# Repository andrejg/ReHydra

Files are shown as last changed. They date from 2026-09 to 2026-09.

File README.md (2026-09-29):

# ReHydra
An adaptation of the Hydra network card for Atari ST/TT/Falcon series of computers, making it work with obtainable modern RJ45 jacks like Hanrun HR911105A.

The original design (https://www.atariworld.org/hardware/hydra/) was done by Mathias Münch in 2009 and published under Attribution-NonCommercial-ShareAlike 4.0.

This rework is published under the same license.

https://creativecommons.org/licenses/by-nc-sa/4.0/legalcode.txt

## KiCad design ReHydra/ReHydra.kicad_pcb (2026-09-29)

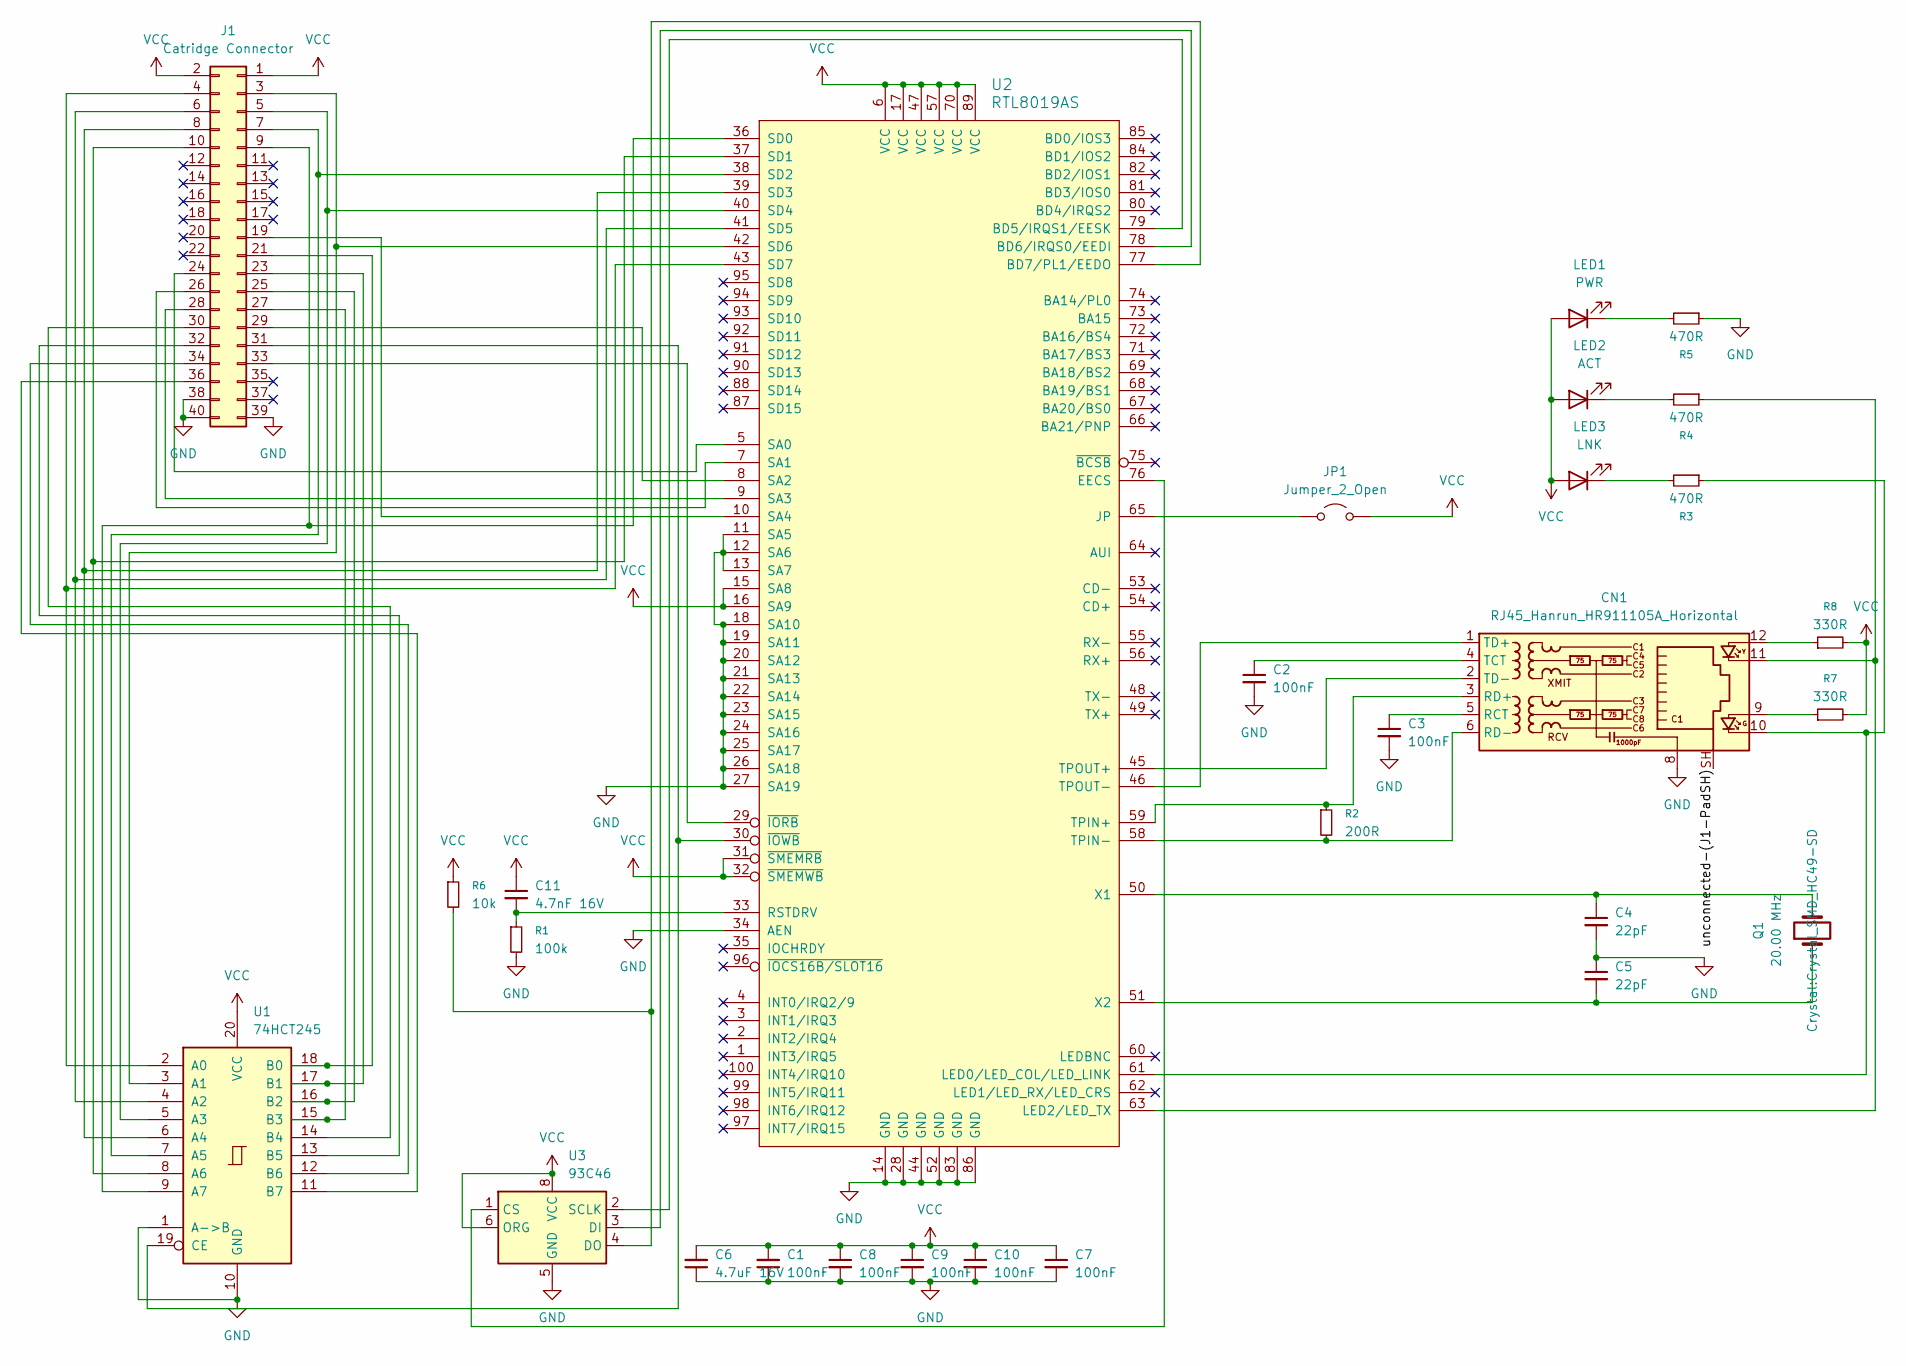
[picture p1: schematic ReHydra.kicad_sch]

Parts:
C1, C2, C3, C7, C8, C9, C10: 100nF; C_0805_2012Metric
C4, C5: 22pF; C_0805_2012Metric
C6: 4.7uF 16V; C_0805_2012Metric
C11: 4.7nF 16V; C_0805_2012Metric
CN1: RJ45_Hanrun_HR911105A_Horizontal
J1: Catridge Connector; Cartridge Connector
JP1: Jumper_2_Open; R_0805_2012Metric
LED1: PWR; LED_0805_2012Metric
LED2: ACT; LED_0805_2012Metric
LED3: LNK; LED_0805_2012Metric
Q1: 20.00 MHz; Crystal_SMD_HC49-SD
R1: 100k; R_0805_2012Metric
R2: 200R; R_0805_2012Metric
R3, R4, R5: 470R; R_0805_2012Metric
R6: 10k; R_0805_2012Metric
R7, R8: 330R; R_0805_2012Metric
U1: 74HCT245; Infineon_SOIC-20W_7.6x12.8mm_P1.27mm
U2: RTL8019AS; PQFP-100
U3: 93C46; SOIC-8_3.9x4.9mm_P1.27mm

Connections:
/unconnected-(J1-PadSH): CN1.SH
GND: C1.1, C2.2, C3.2, C4.2, C5.1, C6.1, C7.2, C8.2, C9.2, C10.2, CN1.8, J1.38, J1.39, J1.40, R1.2, R5.1, U1.1 (A->B), U1.10 (GND), U2.11 (SA5), U2.12 (SA6), U2.13 (SA7), U2.14 (GND), U2.18 (SA10), U2.19 (SA11), U2.20 (SA12), U2.21 (SA13), U2.22 (SA14), U2.23 (SA15), U2.24 (SA16), U2.25 (SA17), U2.26 (SA18), U2.27 (SA19), U2.28 (GND), U2.34 (AEN), U2.44 (GND), U2.52 (GND), U2.83 (GND), U2.86 (GND), U3.5 (GND)
unnamed: CN1.9, R7.1
unnamed: CN1.12, R8.1
unnamed: C3.1, CN1.5 (RCT)
unnamed: CN1.3 (RD+), R2.1, U2.59 (TPIN+)
unnamed: CN1.6 (RD-), R2.2, U2.58 (TPIN-)
unnamed: C2.1, CN1.4 (TCT)
unnamed: CN1.1 (TD+), U2.46 (TPOUT-)
unnamed: CN1.2 (TD-), U2.45 (TPOUT+)
unnamed: J1.3, U1.3 (A1), U2.42 (SD6)
unnamed: J1.4, U1.2 (A0), U2.43 (SD7)
unnamed: J1.5, U1.5 (A3), U2.40 (SD4)
unnamed: J1.6, U1.4 (A2), U2.41 (SD5)
unnamed: J1.7, U1.7 (A5), U2.38 (SD2)
unnamed: J1.8, U1.6 (A4), U2.39 (SD3)
unnamed: J1.9, U1.9 (A7), U2.36 (SD0)
unnamed: J1.10, U1.8 (A6), U2.37 (SD1)
unnamed: J1.19, U2.10 (SA4)
unnamed: J1.21, U1.18 (B0)
unnamed: J1.23, U1.17 (B1)
unnamed: J1.24, U2.5 (SA0)
unnamed: J1.25, U1.16 (B2)
unnamed: J1.26, U2.7 (SA1)
unnamed: J1.27, U1.15 (B3)
unnamed: J1.28, U2.9 (SA3)
unnamed: J1.29, U2.8 (SA2)
unnamed: J1.30, U1.14 (B4)
unnamed: J1.31, U1.19 (CE), U2.30 (~IOWB)
unnamed: J1.32, U1.13 (B5)
unnamed: J1.33, U2.29 (~IORB)
unnamed: J1.34, U1.12 (B6)
unnamed: J1.36, U1.11 (B7)
unnamed: JP1.1 (A), U2.65 (JP)
unnamed: LED1.1 (K), R5.2
unnamed: LED2.1 (K), R4.2
unnamed: LED3.1 (K), R3.2
unnamed: U2.79 (BD5/IRQS1/EESK), U3.2 (SCLK)
unnamed: U2.78 (BD6/IRQS0/EEDI), U3.3 (DI)
unnamed: R6.2, U2.77 (BD7/PL1/EEDO), U3.4 (DO)
unnamed: U2.76 (EECS), U3.1 (CS)
unnamed: CN1.10, R3.1, U2.61 (LED0/LED_COL/LED_LINK)
unnamed: CN1.11, R4.1, U2.63 (LED2/LED_TX)
unnamed: C11.2, R1.1, U2.33 (RSTDRV)
unnamed: C4.1, Q1.2, U2.50 (X1)
unnamed: C5.2, Q1.1, U2.51 (X2)
VCC: C1.2, C6.2, C7.1, C8.1, C9.1, C10.1, C11.1, J1.1, J1.2, JP1.2 (B), LED1.2 (A), LED2.2 (A), LED3.2 (A), R6.1, R7.2, R8.2, U1.20 (VCC), U2.6 (VCC), U2.15 (SA8), U2.16 (SA9), U2.17 (VCC), U2.31 (~SMEMRB), U2.32 (~SMEMWB), U2.47 (VCC), U2.57 (VCC), U2.70 (VCC), U2.89 (VCC), U3.6 (ORG), U3.8 (VCC)

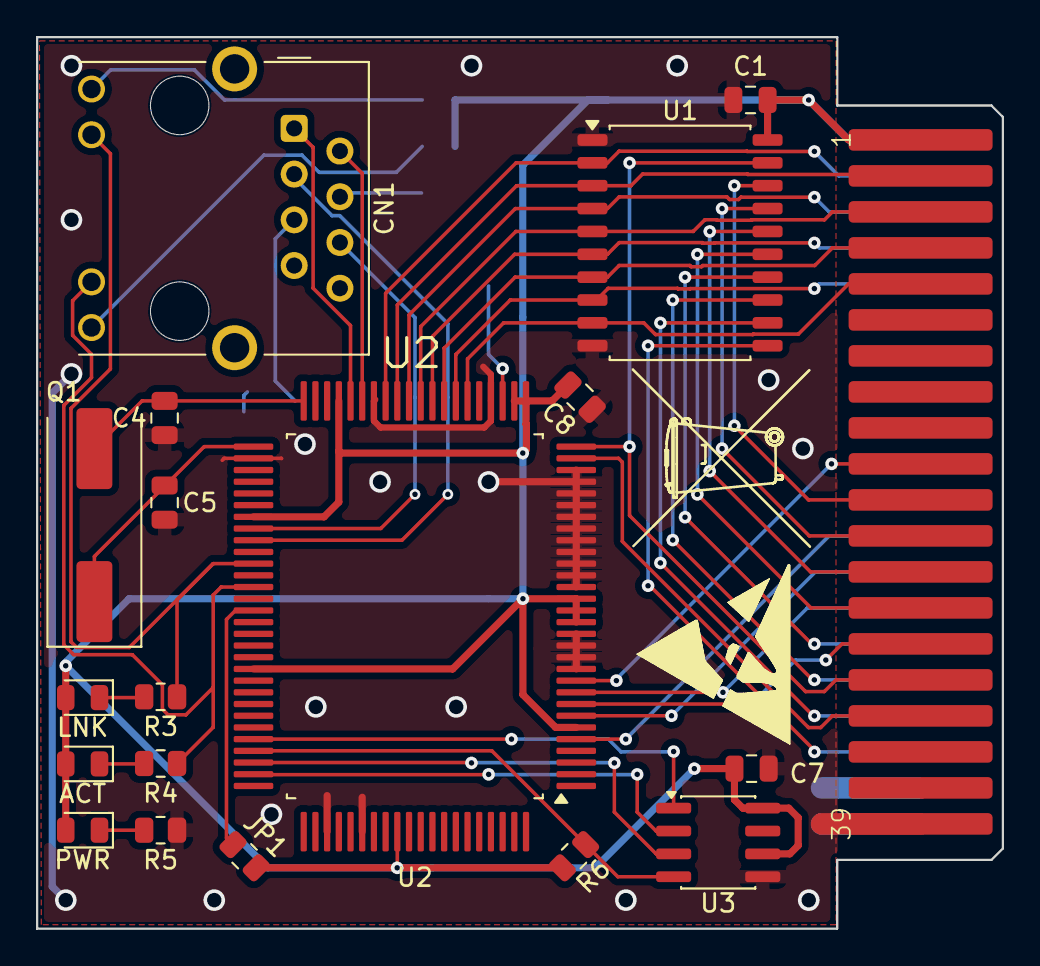
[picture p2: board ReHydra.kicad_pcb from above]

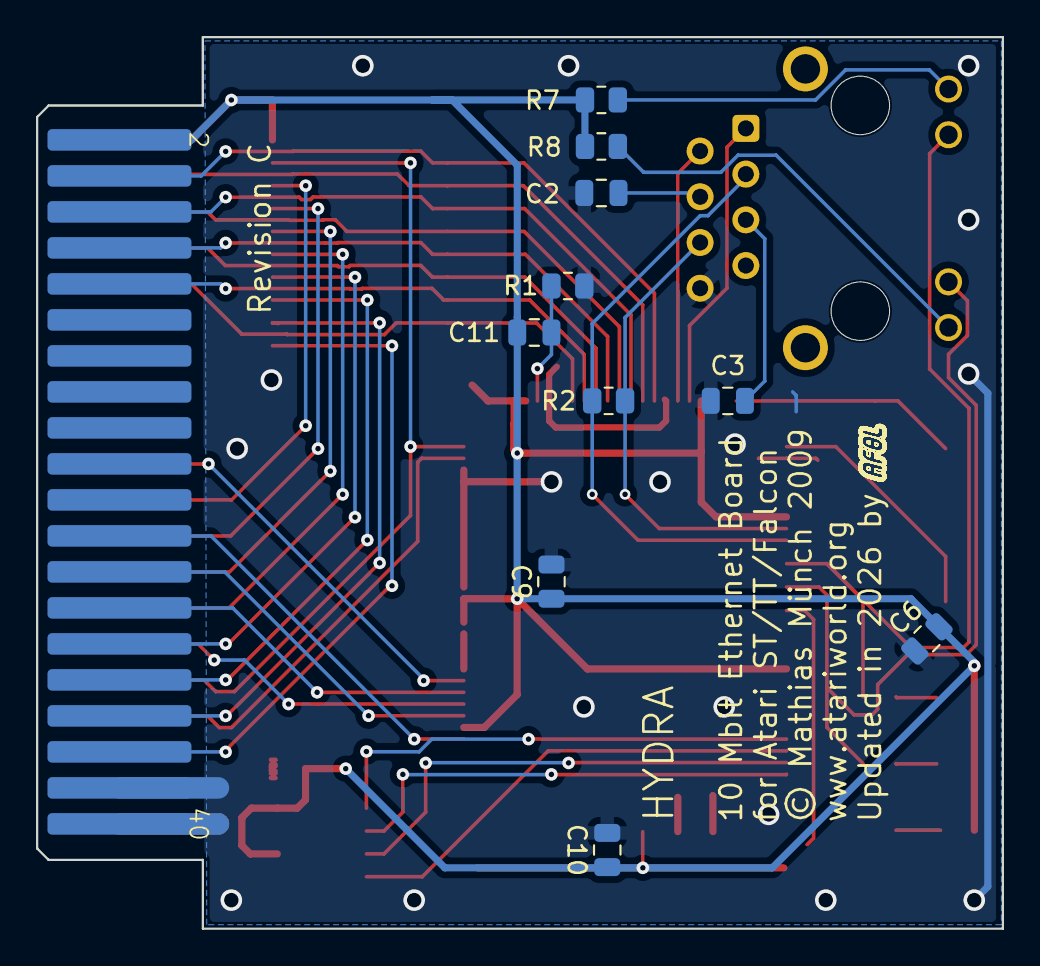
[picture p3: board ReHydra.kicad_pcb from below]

Board: 2 copper layers, 53.7 x 49.5 mm, 29 parts (10 on the bottom side), 46 nets.

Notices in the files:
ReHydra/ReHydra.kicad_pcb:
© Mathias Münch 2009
